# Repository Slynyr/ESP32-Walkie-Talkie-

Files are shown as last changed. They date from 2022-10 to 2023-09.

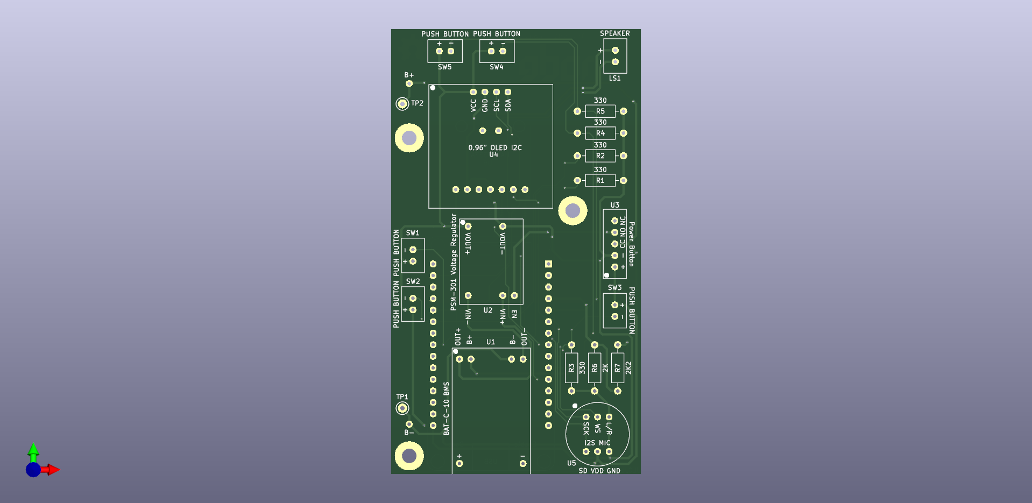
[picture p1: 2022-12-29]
kiCad/Images/WalkieTalkiePCBFront.png

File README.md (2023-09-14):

# ESP32 Walkie-Talkie
All firmware, documentation, and resources are available in the following repository. The ESP32 Walkie-Talkies make use of UDP over wifi in order to transmit audio. They function and operate just like every other Walkie-Talkie but with the benefits of a digital connection rather than an analog one.

## Features
* Oled display
* 12 bit speaker
* Built in battery with charge circuit
* Custom PCB design
* Custom 3d printed housing

## How it Works
The Walkie-Talkie makes use of a wifi enabled chip, the **WROOM-32**, in order to do digital communication via **UDP**. The ESP32 devboard has been modified to house a significantly larger antenna in order to increase the range to a tested 300+ meters. 

## Setup
### Arduino IDE
In order to upload the firmware to the ESP32 Walkie-Talkie, you will need to have the Arduino IDE setup for development on Espressif modules/chips. If you already have the appropriate environemnt setup, skip this step

> Downlaod the [Arduino IDE](https://www.arduino.cc/en/software) for your respective operating system

> Open the Arduino IDE and navigate to **Arduini IDE > Preferences**. Place the following url inside the **Additional board managers URL** box.  
`https://raw.githubusercontent.com/espressif/arduino-esp32/gh-pages/package_esp32_index.json`.

>Navigate to **Tool > Manage Libraries** and install the ***.

### Deploying
> Plug in your ESP32 Devboard and navigate to the **Board Manager** in the top left of your IDE. Select the appropriate board type and port for your respective devboard. If you are using a **WROOM32** based devboard as specified in the **BOM**, use the **WROOM-DA** board manager.
`Note: On some devboards, it may be necesary to hold down the boot button while uploading`

**Clearing Memory**
>Navigate to the **Tools > FlushEEPROM** and open the **FlushEEPROM.ino** file inside the Arduino IDE. We wrote this tool in order to allow us to flush the ESP32's memory. It also validates that all the bytes have been reset. Alternatively, you can use a web version, however, it does do any form of validation.
`https://adafruit.github.io/Adafruit_WebSerial_ESPTool/`

**Flashing Walkie-Talkie firmware**
> Navigate to the main folder and open **Main.Ino** file inside of the Arduino IDE.

## KiCad
The kicad folder contains all the project files, libraries and tools we created throughout the process. The following files can be accessed/opened via KiCad 6.

>Note: In order to properly load the project files in KiCad, you may be required to manually add both the footprint and symbol libraries manualy via the libraries manager in KiCad.

### KiCad Package Manager
Using github for version control can be a little finicky in the case of KiCad. When moving between machines, any non project specific libraries must be manually copied to the repo and then re-copied back in whenever a user pulls. In order to increase iteration time and make the whole process easier, A **CLI** tool was created to handle the copying process

> **SETUP**: When you first load the tool, you will be prompted for a initial setup, simply follow the instructions and input the file paths for both copy paths for KiCad and the Repository. Multiple copy paths can be added by using the "," seperator.

> **Commands:** Libraries can be copied between the source and destination paths by using ***push*** and ***pull*** respectively. The tool can also be reconfigured by running ***config***

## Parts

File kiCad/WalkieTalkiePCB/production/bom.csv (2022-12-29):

Designator | Footprint | Quantity | Value | LCSC Part #
BT1 | BATTERY-CONTACTS | 1 | 18650 Lithium Cell
LS1 | SPEAKER | 1 | Speaker
R1, R2, R3, R4, R5 | R_Axial_DIN0207_L6.3mm_D2.5mm_P10.16mm_Horizontal | 5 | 330
R6 | R_Axial_DIN0207_L6.3mm_D2.5mm_P10.16mm_Horizontal | 1 | 2K
R7 | R_Axial_DIN0207_L6.3mm_D2.5mm_P10.16mm_Horizontal | 1 | 2K2
SW1 | PUSH-BUTTON-CONTACTS | 1 | UP
SW2 | PUSH-BUTTON-CONTACTS | 1 | DWN
SW3 | PUSH-BUTTON-CONTACTS | 1 | MODE
SW4 | PUSH-BUTTON-CONTACTS | 1 | TLK
SW5 | PUSH-BUTTON-CONTACTS | 1 | XTRA
U1 | BAT-C-10TYPEC-BMS | 1 | BAT-C-10TYPEC_(BMS)
U2 | PSM-301-Voltage-Regulator | 1 | PSM-301-Voltage-Regulator-3.3V
U3 | PBS-LED-1606WH-L-Toggle-Switch | 1 | PBS-LED-1606WH-L_(Toggle_Button)
U4 | I2S-128x64-OLED-LCD | 1 | I2C-128X64-OLED-LCD
U5 | I2SINMP441-MIC | 1 | I2S-INMP441_(MIC)
U6 | Amplifier | 1 | MAX98357A
U7 | esp32_devkit_v1_doit | 1 | ESP-WROOM-32

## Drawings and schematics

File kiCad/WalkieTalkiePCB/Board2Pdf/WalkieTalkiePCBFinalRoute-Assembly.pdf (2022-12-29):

1 | 2 | 3 | 4 | 5 | 6 1 | 2 | 3 | 4 | 5 | 6 ABCD | ABCD Date: 2022-12-28 KiCad E.D.A. pcbnew (6.0.0) Size: A4 | Rev: 2.0

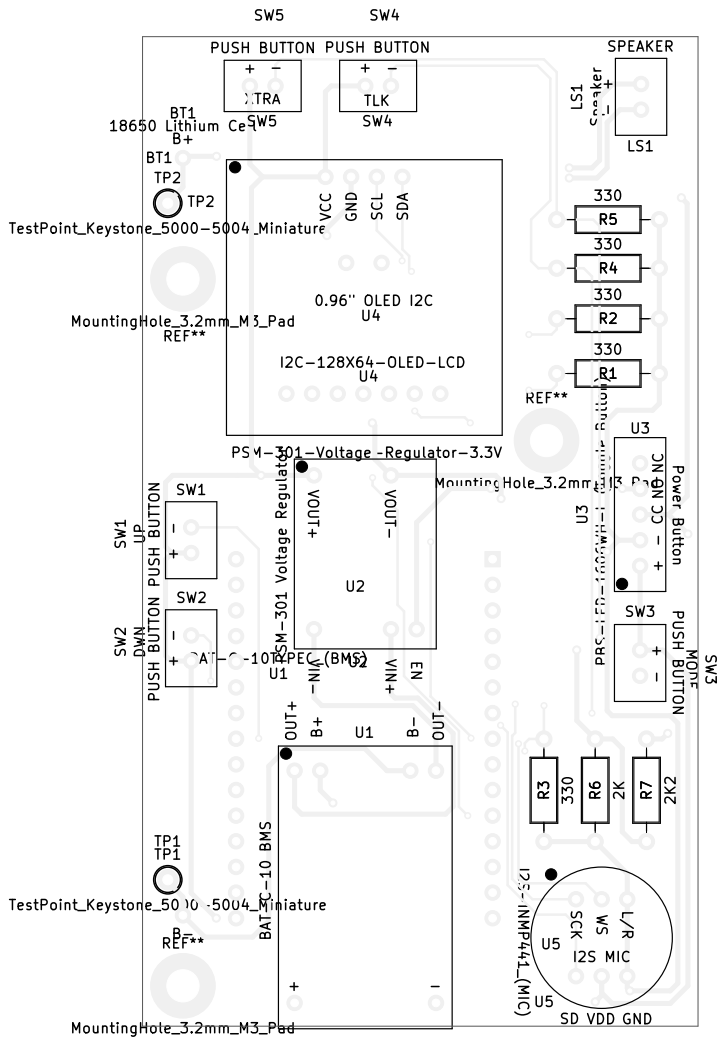
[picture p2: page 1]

Sheet: BlackAndWhiteTop
File: WalkieTalkiePCBFinalRoute.kicad_pcb
Id: 1/1 Title: ESP32 Walkie Talkie - Final Route

1 | 2 | 3 | 4 | 5 | 6

A

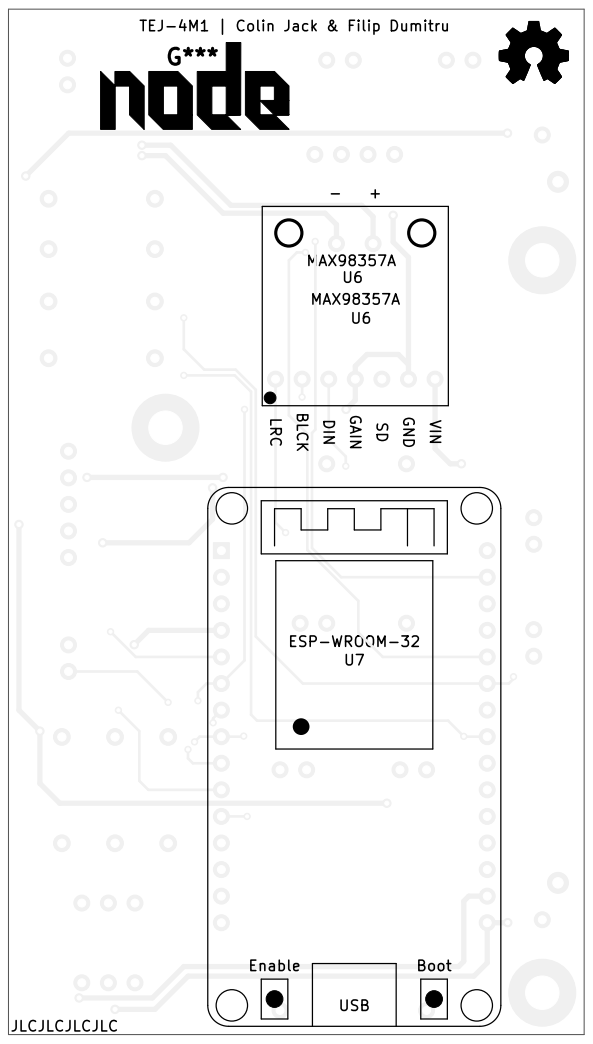
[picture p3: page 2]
D Date: 2022-12-28 KiCad E.D.A. pcbnew (6.0.0) Size: A4; Rev: 2.0; ESP-WROOM-32 MAX98357A; JLCJLCJLCJLC; U7 Enable; Boot USB; U6 BLCK; - MAX98357A LRC; DIN; SD GND VIN; + GAIN

U6 G*** TEJ-4M1 | Colin Jack & Filip Dumitru

File: WalkieTalkiePCBFinalRoute.kicad_pcb Sheet: BlackAndWhiteBottom
Id: 1/1 Title: ESP32 Walkie Talkie - Final Route

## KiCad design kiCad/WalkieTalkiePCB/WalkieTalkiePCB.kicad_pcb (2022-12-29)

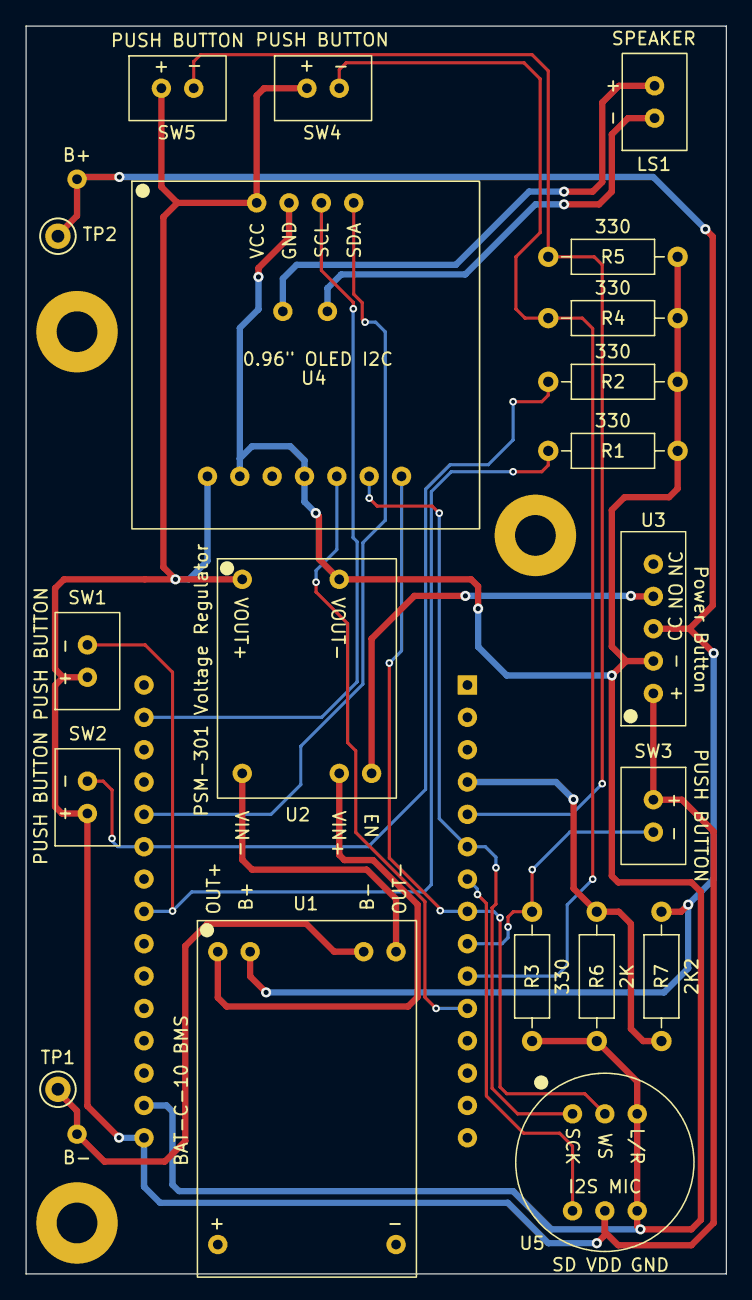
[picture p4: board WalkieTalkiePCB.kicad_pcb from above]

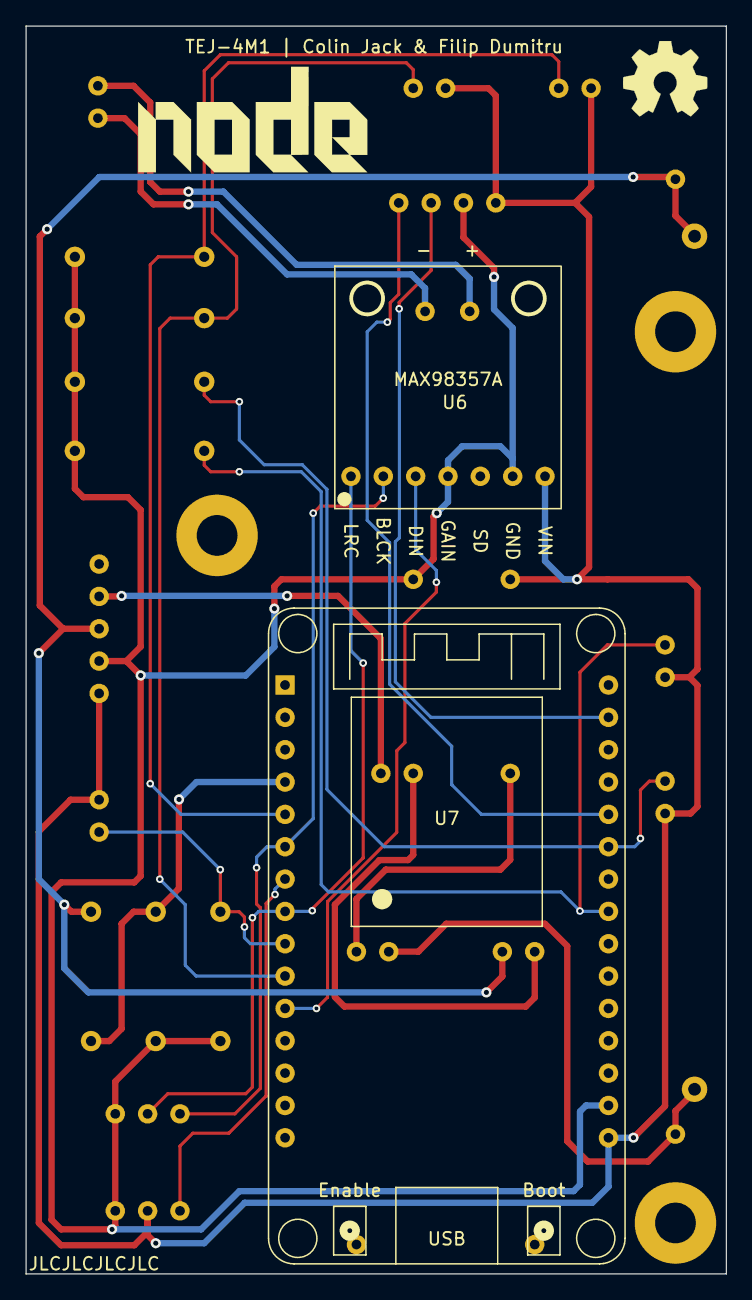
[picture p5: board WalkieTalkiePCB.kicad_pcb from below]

Board: 2 copper layers, 55.0 x 98.0 mm, 23 parts (2 on the bottom side), 21 nets.

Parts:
BT1: 18650 Lithium Cell; BATTERY-CONTACTS
LS1: Speaker; SPEAKER
R1, R2, R3, R4, R5: 330; R_Axial_DIN0207_L6.3mm_D2.5mm_P10.16mm_Horizontal
R6: 2K; R_Axial_DIN0207_L6.3mm_D2.5mm_P10.16mm_Horizontal
R7: 2K2; R_Axial_DIN0207_L6.3mm_D2.5mm_P10.16mm_Horizontal
SW1: UP; PUSH-BUTTON-CONTACTS
SW2: DWN; PUSH-BUTTON-CONTACTS
SW3: MODE; PUSH-BUTTON-CONTACTS
SW4: TLK; PUSH-BUTTON-CONTACTS
SW5: XTRA; PUSH-BUTTON-CONTACTS
TP1, TP2: TestPoint_Keystone_5000-5004_Miniature
U1: BAT-C-10TYPEC_(BMS); BAT-C-10TYPEC-BMS
U2: PSM-301-Voltage-Regulator-3.3V; PSM-301-Voltage-Regulator
U3: PBS-LED-1606WH-L_(Toggle_Button); PBS-LED-1606WH-L-Toggle-Switch
U4: I2C-128X64-OLED-LCD; I2S-128x64-OLED-LCD
U5: I2S-INMP441_(MIC); I2SINMP441-MIC
U6: MAX98357A; Amplifier
U7: ESP-WROOM-32; esp32_devkit_v1_doit

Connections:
GND: R1.1, R2.1, R3.1, R4.1, R5.1, R6.1, U2.2 (VOUT-), U3.2 (-), U4.2 (GND), U5.3 (L/R), U5.6 (GND), U6.4 (GAIN), U6.6 (GND), U7.29 (GND)
unnamed: BT1.1 (+), R7.2, TP2.1, U1.2 (B+), U3.3 (CC)
unnamed: BT1.2 (-), TP1.1, U1.3 (B-)
unnamed: R1.2, SW1.2, U7.23 (D5)
unnamed: R2.2, SW2.2, U7.21 (D19)
unnamed: R3.2, SW3.2, U7.9 (D26)
unnamed: R4.2, SW4.2, U7.10 (D27)
unnamed: R5.2, SW5.2, U7.5 (D35)
unnamed: R6.2, R7.1, U7.4 (D34)
unnamed: U1.1 (OUT+), U2.4 (VIN+)
unnamed: U1.4 (OUT-), U2.3 (VIN-)
unnamed: U2.5 (EN), U3.4 (NO)
unnamed: U4.3 (SCL), U7.17 (D22)
unnamed: U4.4 (SDA), U7.20 (D21)
unnamed: U5.1 (SCK), U6.2 (BLCK), U7.6 (D32)
unnamed: U5.2 (WS), U6.1 (LRC), U7.8 (D25)
unnamed: U5.4 (SD), U7.7 (D33)
unnamed: U6.3 (DIN), U7.11 (D14)
unnamed: LS1.1, U6.8 (-)
unnamed: LS1.2, U6.9 (+)
VCC: SW1.1, SW2.1, SW3.1, SW4.1, SW5.1, U2.1 (VOUT+), U3.1 (+), U4.1 (VCC), U5.5 (VDD), U6.7 (VIN), U7.30 (3V3)

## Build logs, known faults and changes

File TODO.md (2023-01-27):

# TODO

## Power Optimization
- Power management menu
  - [ ] Lower clock speed
  - [ ] Change display timeout
  - [ ] Change display brightness

## Networking
- [x] Channel Selection and communication
- [ ] ~~ESP-NOW Encryption~~
- [ ] ~~Node Mode using VoIP~~
- [x] Channel Count

## I2S Audio
- [x] Get data from microphone
- [x] Split it into groups of 250 bytes & transmit
- [x] Store incoming audio in circular buffer & play over speaker
- [x] Talk control - no audio is played when talk button is held
- [ ] Channel sweep for activity with fft
- [x] Specific process core pinning (I2S Core 1, all other functions core 0) 

## Hardware
- [x] Screen navigation buttons
- [x] Talk button
- [x] Hook up battery sens
- [x] BMS + Voltage Reg
- [x] Power Switch
- [x] Audio
- Case
  - [ ] CAD
  - [ ] Printing
  - [ ] Assembly

## Screen Menus
- [ ] Power Management Menu
- [ ] Update connection icons
- [ ] UDP Connection Icon
- [ ] Node Mode Screen
- [ ] Debug Menu  
  - [ ] Test buttons
  - [ ] Reset battery config
  - [ ] Test Display
  - [ ] Test audio passthrough

## Extras
- [ ] Stats (Power on time, Battery cycles, Talk time)

## General
- [ ] Sanitize KiCAD Files

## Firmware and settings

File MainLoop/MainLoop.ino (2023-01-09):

#include "UpdateDisplay.h"
#include "ExternalIO.h"
#include "P2PConnect.h"
#include "I2S-Audio.h"
#include "configurator.h"

unsigned long previousBatteryMillis = 0;

void setup() {
  Serial.begin(115200);

  initializeConfigurator();
  //initializes configurator

  //Specific Init Order DO NOT CHANGE!
  //Initialize P2P
  P2PInitialize();

  //Initialize Display
  displayInitialize();

  //Get first battery voltage
  batteryIndicatorValues();

  //Initialize inputs
  inputsInitialize();

  //Initialize I2S
  i2s_init();

  //Start multicore I2S
  i2s_startTask();
}

void loop() {
  //Update millis
  unsigned long currentMillis = millis();

  getP2PMillis(currentMillis);

  getDisplayMillis(currentMillis);

  //Update display
  displayUpdate();

  //Update IO Values
  ioUpdate();

  //Broadcast demo
  //broadcast("AMONGUS");

  //Audio broadcast
  audioBroadcast();

  //Pass battery value to display every 10s
  if (currentMillis - previousBatteryMillis >= 10000) {
    previousBatteryMillis = currentMillis;
    batteryIndicatorValues();
  }

  compareActiveRollingArray();

  configurator();
}

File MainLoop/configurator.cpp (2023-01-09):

#include "UpdateDisplay.h"
#include "configurator.h"
#include "ExternalIO.h"

//predefined memory address for battery offset and configurator status 
const int isConfigCompleteAddr = 10;
const int batteryOffsetAddr = 100; //tbd

bool ignoreConfig = false; //debug
bool forceConfig = false; //debug
bool isConfigComplete = false;
float actualBatteryVoltage = 0.f; 
float batteryOffset = 0.f; 
float serialRead = 0.f;

void configureBatteryOffset(){
    Serial.printf("Wrote %.2f to memory\n", actualBatteryVoltage);
    EEPROM.put(isConfigCompleteAddr, true);
    EEPROM.put(batteryOffsetAddr, calculateTolerance());
    EEPROM.commit();
    EEPROM.get(isConfigCompleteAddr, isConfigComplete); 
    EEPROM.get(batteryOffsetAddr , batteryOffset); 
    Serial.printf("Current isConfigComplete value in memory: %d\n", isConfigComplete);
    Serial.printf("Current batteryOffset value in memory: %.2f\n", batteryOffset);
}

void serialManagerBatteryConfig() {
    Serial.println("[CONFIG] Warning: Input current battery voltage into the serial monitor in order to complete setup process");

    drawText(true, 64, 32, 3, "Configure Battery", "WHITE");

    serialRead = Serial.parseFloat();
    //Serial.printf("serialRead=%.2f\n", serialRead);
    if (serialRead != 0){
      actualBatteryVoltage = serialRead;
      configureBatteryOffset();
    }
}

float calculateTolerance(){
  float readVoltageLevel = ((pollBattery() * 4.2) / 2205);
  float toleranceModifier = 0;
  if (readVoltageLevel != 0){
    toleranceModifier = (actualBatteryVoltage / readVoltageLevel);
  } else {
    Serial.println("[WARN] Battery voltage returned zero. Defaulted battery offset to 0");
  }

  //Serial.printf("ReadVoltage: %.2f ActualBatteryVoltage: %.2f BatteryOffset: %.2f", readVoltageLevel, actualBatteryVoltage, toleranceModifier); //BROKEN | ARDUINO pritf does not properly support %f. 
  Serial.printf("actualBatterVoltage: %.2f\n", actualBatteryVoltage);
  Serial.printf("toleranceModifier: %.2f\n", toleranceModifier);
  Serial.printf("readVoltageLevel: %.2f\n", readVoltageLevel);
  return toleranceModifier;
}

void initializeConfigurator(){
  EEPROM.begin(255);

  EEPROM.get(batteryOffsetAddr, batteryOffset);
  EEPROM.get(isConfigCompleteAddr, isConfigComplete);

  Serial.printf("BatteryOffset: %.2f\n", batteryOffset);
}

void configurator(){
  if (!ignoreConfig && !isConfigComplete || forceConfig){
      serialManagerBatteryConfig();
  }
}

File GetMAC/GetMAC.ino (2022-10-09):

// Complete Instructions to Get and Change ESP MAC Address: https://RandomNerdTutorials.com/get-change-esp32-esp8266-mac-address-arduino/

#include "WiFi.h"
 
void setup(){
  Serial.begin(115200);
  Serial.print("MAC:");
  WiFi.mode(WIFI_MODE_STA);
}
 
void loop(){
  Serial.println(WiFi.macAddress());
}

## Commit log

2022-10-07 Battery indicator
    -ESP can now calculate voltage level based on battery
    -Dynamic battery level indicator
2022-10-07 Add Voltage Readout
2022-10-08 Added backdrop modes
    Added the ability to switch between UI backdrops
2022-10-09 Improve voltage accuracy
    -Added state change function
    -Added low voltage popup
2022-10-12 Fixed state machine for battery Notification
    - Added battery low notification
    - Added debug button in order to dismiss notification
    - Added isActiveNotification bool which allows lower-screen elements to be easily hidden for other notifications in the future. This allows us to remain in the same state while still displaying notifications.
2022-10-12 Button input system updated
    - Fixed button input system
    - NEW COMPILE ERROR in UpdateDisplay.h - To be resolved
2022-10-12 Change voltage math
    -More accurate voltage tracking
    -PB to dismiss works now
2022-10-14 Defining macAddress parsing
    - defined functions required to parse incoming mac-addresses and for keeping track of active mac-addresses
2022-10-15 WILL NOT COMPILE. Mac Address logic update
    Will need to rework some logic to support vectors since we are now passing strings
    [MainLoop.ino]
2022-10-20 Bugfixes and Refactoring
    - Created corresponding cpp files for each h file
    - Fixed MAC count compile errors
    - New bug where if they try to count a peered user, one will significantly slow down and loop
    [ExternalIO.cpp, MainLoop.ino, P2PConnect.cpp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]
2022-10-21 Debugging print statements & formatting
2022-10-23 Fix ESP crashing & bootloop
    [P2PConnect.cpp]
2022-10-24 Rewrite using arduino arrays
    - Rename types to strings
2022-10-25 Got User Count Working
    - Lowered loading screen time
    - Raised battery poll time
2022-10-26 Long press button interaction
    Added first test of long press and short press button interaction for up button (temporarily binded the same as debug button)
    [ExternalIO.cpp, UpdateDisplay.cpp]
2022-10-31 Fixed finding empty array slot bug
    [MainLoop.ino, P2PConnect.cpp, UpdateDisplay.cpp]
2022-10-31 Debug Tests
    - Added dumpArray Function for printing all contents of a given array to serial.
2022-11-06 Fixed P2PConnect MacAddress logging
    - Fixed Mac Address logging for P2PConnect
    - User count now works
    [MainLoop.ino, P2PConnect.cpp, UpdateDisplay.cpp]
2022-11-08 Update pushbutton function - Unverified - Won't work
    - Button status will clear due to being a local variable
    - Must keep a set of global variables for each button
    [ExternalIO.cpp, MainLoop.ino, UpdateDisplay.cpp]
2022-11-08 Create button structure
2022-11-08 Reformat buttons to be checked within the function
2022-11-09 Button Input System Debugging & Fixes
    - buttons structure and array declaration now in header file
    [ExternalIO.cpp, UpdateDisplay.cpp]
2022-11-09 Incomplete millis based P2P implementation
    - Generated new folder for temp scripts
    - Included incomplete P2P millis script
2022-11-09 Testing buttons
2022-11-11 Fixed Button Function
    - Fixed Button Function
    - Added channel counter
    [ExternalIO.cpp, UpdateDisplay.cpp]
2022-11-13 Fix short press unresponsive
    [UpdateDisplay.cpp]
2022-11-30 Created KiCad Project
    [WalkieTalkie.kicad_pcb, WalkieTalkie.kicad_sch]
2022-12-01 Battery Monitor Fix
2022-12-01 KiCad Schematic Update
    [WalkieTalkie.kicad_sch, WalkieTalkiePCB.kicad_pcb, WalkieTalkiePCB.kicad_sch]
2022-12-02 Bug fixes and visual changes to user prompts
    [UpdateDisplay.cpp, configurator.cpp]
2022-12-08 Kicad Update
2022-12-15 Fix I2S Mic
    - IDF bug, where channels are swapped, change to right channel
    [ExternalIO.cpp]
2022-12-19 Kicad Footprints
2022-12-24 Updated PCB schematic
    [WalkieTalkiePCB.kicad_sch]
2022-12-24 Kicad Finalized Schematic
    Colin Jack is smort
    [WalkieTalkiePCB.kicad_sch]
2022-12-24 Update Button Pins
2022-12-28 PCB
    Why do we live. Just to suffer.
    [WalkieTalkiePCB.kicad_pcb, WalkieTalkiePCB.kicad_sch]
2022-12-29 Final Route of PCB
    - Generated JLC gerber
    - Created BOM
    [WalkieTalkiePCB.kicad_sch, WalkieTalkiePCBFinalRoute.kicad_pcb, bom.csv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]
2022-12-29 Moved Silkscreen Elements
    Slikscreen
    [WalkieTalkiePCBFinalRoute.kicad_pcb]
2022-12-29 Update Gerber
2022-12-29 Repo Formatting & Kicad update
2022-12-29 Updated Schematic Annotation
    [WalkieTalkiePCB.kicad_pcb, WalkieTalkiePCB.kicad_sch, WalkieTalkiePCBFinalRoute.kicad_pcb]
2023-01-07 Audio Receiving and Sending
    - Talk button states
    - Fixed debug passthrough state
    - Updated Todo
    [ExternalIO.cpp, MainLoop.ino, P2PConnect.cpp]
2023-01-07 Fix Watchdog Timer Trip
2023-01-07 Optimize Audio
    - Replace I2S start and stop with zeroing TX buffer
    [MainLoop.ino]
2023-01-09 Updated Configurator and Update Display
    - Configurator now works and has integrated calculations for battery offset
    - Configurator now has an initializer in order to retrieve stored values on boot
    - pretified Options menu
    - created uiHeader() method
    - Updated old method that didnt use new input system
    - Created tool for flushing EEPROM memory
